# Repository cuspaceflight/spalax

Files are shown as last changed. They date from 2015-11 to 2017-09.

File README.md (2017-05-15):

# Spalax



This repository contains the schematics, PCB designs and firmware for a 10DOF IMU system.

## Components

- [Firmware](firmware) - Firmware for the various IMU boards
- [GUI](gui) - A 3D visualisation GUI which renders in realtime data sent from an attached IMU board
- [Shared](shared) - A static library providing common functionality between the various software components
- [Util](util) - A collection of useful C++, python and bash utilities
- [PCB](pcb) - The KiCad PCB files for the Spalax IMU boards

## Build Requirements

- GCC v4.8+
- CMake v3.2+
- arm-none-eabi-gcc (firmware build)
- xorg-dev libgl1-mesa-dev libfreetype6-dev libglew-dev libglm-dev (GUI build)
- GLFW v3+ (GUI build) - see [glfw-install.sh](util/bash/glfw-install.sh)

## Compilation

Having installed all the dependencies simply run from the root directory of the repo

```bash
git submodule update --init --recursive
./util/bash/travis-build.sh
```

This will configure and compile all the different components. If you only wish to configure a subset, just run the relevant section of [travis-build.sh](util/bash/travis-build.sh).

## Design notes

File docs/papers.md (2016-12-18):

[quadruped kalman filter design](http://biorob.epfl.ch/files/content/sites/biorob/files/users/195094/imports/report.pdf) 

[automatic and adaptive sensor calibration](http://ac.els-cdn.com/S0307904X07000297/1-s2.0-S0307904X07000297-main.pdf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)

[GPS/IMU Data Fusion](http://www.stats.ox.ac.uk/~caron/Publications/J_Information_Fusion_2004.pdf)

[Iterative calibration for triaxial accelerometers](http://www.ncbi.nlm.nih.gov/pmc/articles/PMC3436022/)

[Quaternion based kalman filter](http://ieeexplore.ieee.org/stamp/stamp.jsp?tp=&arnumber=4020379)

[High-Efficiency Low-Cost Accelerometer-Aided Gyroscope Calibration](http://ieeexplore.ieee.org/stamp/stamp.jsp?tp=&arnumber=5412920)

[Kalman filter introduction videos](http://studentdavestutorials.weebly.com/kalman-filter-with-matlab-code.html)

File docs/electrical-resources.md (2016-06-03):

# Resources for Electronics Design

## CPU

We plan to use the
[STM32F405VG](http://www.st.com/web/en/catalog/mmc/FM141/SC1169/SS1577/LN1035/PF252142?s_searchtype=keyword)
ARM Cortex-M4 based micro controller as the CPU for the board. Some useful
resources:

* [Datasheet](http://www.st.com/st-web-ui/static/active/en/resource/technical/document/datasheet/DM00037051.pdf)
* [Reference manual](http://www.st.com/web/en/resource/technical/document/reference_manual/DM00031020.pdf)
* [Programming manual](http://www.st.com/web/en/resource/technical/document/programming_manual/DM00046982.pdf)

For reference, STMicroelectronics make available the schematics for their "STM32F4Discovery" board from the 
[corresponding page](http://www.st.com/web/catalog/tools/FM116/SC959/SS1532/PF252419) on their website.

## Sensor modules

The main sensor module is a [ADIS16405BMLZ MEMS
Module](http://onecall.farnell.com/analog-devices/adis16405bmlz/ic-module-gyro-accel-mag-24pin/dp/1849515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).

* [Datasheet](http://www.farnell.com/datasheets/1914493.pdf)

The secondary sensor module is an MPU9250

* [Datasheet](<https://www.invensense.com/wp-content/uploads/2015/02/MPU-9250-Datasheet.pdf>)
* [Register Map](<https://www.invensense.com/wp-content/uploads/2015/02/MPU-9250-Register-Map.pdf>)
* [Internal Magnetomer Datasheet](<https://www.akm.com/akm/en/file/datasheet/AK8963C.pdf>)

## Other components

* [ADP3335 voltage regulator](http://www.analog.com/media/en/technical-documentation/data-sheets/ADP3335.pdf)
* [USBLC6-2 ESD protection](http://www.st.com/web/en/resource/technical/document/datasheet/CD00050750.pdf)

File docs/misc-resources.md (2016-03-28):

### Papers:

* [Stochastic modeling of MEMS sensors](http://www.cit.iit.bas.bg/cit_2010/v10-2/31-40.pdf)
* [Attitude Estimation Using Modified Rodrigues Parameters](http://ntrs.nasa.gov/archive/nasa/casi.ntrs.nasa.gov/19960035754.pdf)
* [Analog Device's Application Note on the EKF implementation in another of their sensors](http://www.analog.com/media/en/technical-documentation/application-notes/AN-1157.pdf)
* [A Survey of Nonlinear Attitude Estimation Methods](http://ancs.eng.buffalo.edu/pdf/ancs_papers/2007/att_survey07.pdf)

### Existing projects:

* https://github.com/sfwa/ukf
* [An existing sensor](https://www.bosch-sensortec.com/en/homepage/products_3/sensor_hubs/iot_solutions/bno055_1/bno055_4) which does sensor fusion whose SPI interface we may take inspiration from.
* https://github.com/kriswiner/BNO-055 - A driver for the above which does
    attitude estimation on an Arduino via a quaternion filter
* http://www.x-io.co.uk/res/doc/madgwick_internal_report.pdf - An efficient
    orientation filter for inertial and inertial/magnetic sensor arrays (Some
    existing work on putting this into some efficient embedded C)
    
### Other resources:

* [IMU quadrotor dataset](http://www.sfly.org/mav-datasets)
* [A Collection of Outdoor Robotic Datasets with centimeter-accuracy Ground Truth](http://www.mrpt.org/malaga_dataset_2009)
* [Handheld camera 6dof trajectories](http://webdav.is.mpg.de/pixel/benchmark4camerashake/)

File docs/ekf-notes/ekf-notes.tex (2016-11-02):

\documentclass[a4paperz]{paper}

\usepackage{amsmath}
\usepackage{amssymb}
\usepackage{microtype}
\usepackage{times}

\title{Some notes on Extended Kalman Filters for Spacecraft Attitude Estimation}
\author{Rich Wareham}

\begin{document}
\maketitle

\section{Introduction}

These notes provide a heavily abbreviated summary of the use of the extended
Kalman filter and modified Rodrigues rotation parametrisation in spacecraft
attitude estimation. More detailed information can be found in
\cite{crassidis1996attitude, karlgaard2009nonsingular} but it is hoped that this
note provides a concise reference for the concepts contained within those
papers.

We begin with a review of two common parametrisations for rotations in
$\mathbb{R}^3$, quaternions and the modified Rodrigues vector. We then define
the state vector used to represent the current state of the spacecraft and which
is updated by the Kalman filter. The various sensor measurement functions are
then defined and finally we outline the complete Kalman filter algorithm.

\section{Review of quaternions}

The set of quaternions is conventionally denoted as $\mathbb{Q}$. This set can
be associated with analogues of multiplication and addition to form a ring.  A
convenient parametrisation of a given quaternion is in terms of a
\emph{scalar} or ``real'' part and three independent \emph{vector} or
``imaginary'' parts:
$$
q \equiv q_1 + q_i \mathbf{i} + q_j \mathbf{j} + q_k \mathbf{k}
$$
where $q_{\{1,i,j,k\}} \in \mathbb{R}$ and
$$
\mathbf{i}^2 = \mathbf{j}^2 = \mathbf{k}^2 = \mathbf{ijk} = -1.
$$

A unit quaternion, $q$, is one where $q^2 = 1$. Quaternion conjugation is
defined analogously to complex numbers:
$$
\left(
	q_1 + q_i \mathbf{i} + q_j \mathbf{j} + q_k \mathbf{k}
\right)^* \triangleq
	q_1 - q_i \mathbf{i} - q_j \mathbf{j} - q_k \mathbf{k}
$$
It should be clear from the above that both $\mathbb{R}$ and $\mathbb{C}$ are
sub-groups of $\mathbb{Q}$.

We state without proof that the unit quaternion may be interpreted as
representing a rotation in $\mathbb{R}^3$. Identifying $\mathbf{i}$,
$\mathbf{j}$ and $\mathbf{k}$ with some Cartesian basis of $\mathbb{R}^3$ we may
bijectively map any vector $v \in \mathbb{R}^3$ to $\mathbb{Q}$. In so doing,
the transformation
$$
v' \leftarrow q \, v \, q^*
$$
with $q^2 = -1$ represents some rotation of $v$. Letting $\bar{n} = n_i
\mathbf{i} + n_j \mathbf{jk} + n_k \mathbf{k}$ be the unit vector pointing along
the axis of rotation and $\theta$ be the rotation angle, we find that the
quaternion representing the equivalent rotation is given by
$$
q = \cos\left(\theta / 2\right) + \sin\left(\theta / 2\right) \bar{n}.
$$

\section{Review of the modified Rodrigues parameterisation}

Below, we will be using the \emph{Modified Rodrigues Parameters} representation.
Letting $\left< q\right>_s$ and $\left< q\right>_v \equiv \left< q \right>_i
\mathbf{i} + \left< q\right>_j \mathbf{j} + \left< q\right>_k \mathbf{k}$ be the
scalar (real) and vector (imaginary) components of the quaternion $q$, we have
the MRP representation of $q$ defined to be
$$
\mbox{mrp}(q) \triangleq \frac{1}{1 + \left< q\right>_s} \left< q
\right>_v \equiv \bar{n} \tan \left( \frac{\theta}{4} \right)
$$
where $\bar{n}$ is the unit vector pointing along the axis of rotation and
$\theta$ is the angle of rotation. In particular, note that $\mbox{mrp}(1) =
\vec{0}$.

\section{Representation of spacecraft state}

In this section we outline the formation of the \emph{state vector}, $x_k$,
which we use to represent the state of the spacecraft at time instant $k$.

We firstly define two frames of reference. The \emph{reference frame} is the
absolute frame. Conventionally we may choose the $z$ direction to be ``up'' and
define $x$ and $y$ with respect to some horizontal reference. (We may choose $x$
to be East and $y$ to be North, for example.) The \emph{body frame} is defined
relative to the spacecraft. In this case $z$ may be along the principal thrust
axis and $x$ and $y$ may be defined with reference to some known point of
reference on the spacecraft body.

Attitudes of spacecraft are usually represented as rotations mapping the
reference frame to the spacecraft body frame. Define $q_k \in \mathbb{Q}$ to be
the unit quaternion representing the rotation from the reference frame to the
body frame at timestep $k$. Further let $\omega_k \in \mathbb{R}^3$ be the
reference frame angular velocity vector of the spacecraft at timestep $k$.

We use the notation $\dot{x}$ to denote the differential of $x$ with respect to
time. Hence we will use $\ddot{p}_k$ to represent the linear acceleration of the
spacecraft. For attitude estimation, it is assumed that this is simply the
acceleration due to gravity.

There is an issue with using the attitude as represented by a quaternion
directly in a Kalman filter. The interdependence of the four components of $q_k$
is highly non-linear and, relatedly, the four components are a redundant
parameterisation. We wish to use a quaternion representation, however, because
it does not suffer from singularities of representation.

To work around this problem we shall instead keep track of the
timestep-to-timestep \emph{error} in attitude, $\Delta q_k \in \mathbb{Q}$.
I.e., $q_k = \Delta q_k \, q_{k-1}$. Further we will represent $\Delta
q_k$ with the three-parameter MRP representation. As long as the error
remains far from the representation's singular points there shouldn't be a
problem. In the case of the MRP, this means that the spacecraft should not
rotate more than $180^\circ$ in one timestep.

We will be sensing orientation by integrating measurements from gyroscopes
assumed to have some bias. Let $b_k$
represent the gyro bias at timestep $k$ such that the gyro measurement
$\omega^{(g)}_k$ is related to the true body-frame angular velocity,
$\omega^{(b)}_k$ by
$$
\omega^{(g)}_k = \omega^{(b)}_k + b_k + \nu^{(g)}_k
$$
where $\nu^{(g)}_k$ is the gyro noise at time $k$ whose components are assumed
to be i.i.d. samples from some zero-mean Gaussian process. The gyro bias, $b_k$,
is assumed to be a Gaussian random walk. (I.e., $\dot{b}_k$ are drawn from some
stationary zero-mean Gaussian process.)

In order to allow for gyro bias in our model, we shall estimate the
instantaneous gyro bias $b_k$ as part of the state vector. Our complete state
vector is therefore
$$
x_k \triangleq \left[
	\mbox{mrp}(\Delta q_k), \omega_k, \dot{\omega}_k, b_k
\right]
$$
and has 12 components. The zero-noise kinematics of the state components may now
be written directly:
$$
\frac{\partial}{\partial t} \mbox{mrp}(\Delta q_k) = 0, \quad
\frac{\partial}{\partial t} \omega_k = \dot{\omega}_k, \quad
\frac{\partial}{\partial t} \dot{\omega}_k = 0, \quad
\frac{\partial}{\partial t} b_k = 0.
$$

We shall split estimates relating to timestep $k$ into \emph{a priori} and
\emph{a posteriori} classes. Estimates which are $\emph{a priori}$ are formed
from all measurements \emph{prior} to timestep $k$ whereas $\emph{a
posteriori}$ estimates additionally take into account measurements from timestep
$k$.

Our \emph{a priori} state prediction step is therefore a simple Euler integration:
$$
\hat{x}_{k|k-1} = f\left(\hat{x}_{k-1|k-1}; \Delta t\right)
\triangleq \hat{x}_{k-1|k-1} + \Delta t \frac{\partial}{\partial t}
\hat{x}_{k-1|k-1}.
$$

In addition we set $\mbox{mrp}(\hat{\Delta q}_{k|k-1}) = \vec{0}$ to reflect our
belief that the prediction error is zero and we also set
$\hat{\dot{\omega}}_{k|k-1} = \vec{0}$ to reflect our belief that there is no
imposed angular acceleration. In the case of active control, this last
assumption should be replaced with the angular acceleration vector due to
applied thrust.

The Jacobian of $f(\cdot)$ at $\hat{x}_{k-1|k-1}$ with respect to the state
vector components, $F_k$, may be written down directly from the definition of
the differential above.

For each time step, $k$, we wish to obtain the \emph{a posteriori} attitude
estimate $\hat{q}_{k|k}$. We can calculate it from the \emph{a priori} and
\emph{a posteriori} state estimates $\hat{x}_{k|k-1}$ and $\hat{x}_{k|k}$.
(Notice that in general we use $\hat{\cdot}$ to indicate the estimates of states
and their components as opposed to their ``true'' values.) Define the \emph{a
priori} estimate of attitude to be
$$
\hat{q}_{k|k-1} \triangleq q^{\Delta t}_{\hat{\omega}_{k-1|k-1}}
\hat{q}_{k-1|k-1}
$$
where $q_{\hat{\omega}_{k-1|k-1}}$ is a rotation around the axis aligned with
$\hat{\omega}_{k-1|k-1}$. The angle of the rotation is the magnitude of
$\hat{\omega}_{k-1|k-1}$.

The \emph{a posteriori} estimate of attitude is obtained by applying the
estimated error quaternion:
$$
\hat{q}_{k|k} \triangleq \hat{\Delta q}_{k|k} \hat{q}_{k|k-1}.
$$

\section{Measurement functions}

The accelerometer measurement function is
$$
h_a(x_k; \hat{q}_{k|k-1}) = q'_k \, g \, {q'_k}^*
$$
where $g$ is the vector acceleration due to gravity in the reference frame and
$q'_k \triangleq \hat{\Delta q}_{k|k-1} \, \hat{q}_{k|k-1}$. 

The gyroscope measurement function is
$$
h_g(x_k; \hat{q}_{k|k-1}) = q'_k \, \omega_k \, {q'_k}^* + b_k.
$$

The magnetometer measurement function is
$$
h_B(x_k;\hat{q}_{k|k-1}) = q'_k \, \frac{B}{|B|} \, {q'_k}^*
$$
where $B$ is the local reference-frame magnetic field vector.

Note that, in general, $g$ and $B$ are a function of $p_k$. For the sake of
considering attitude-only motion, we assume that they are fixed and known.

For each measurement function we may also write down the Jacobian, $H_k$,
centred on $\hat{x}_{k|k-1}$ with respect to the state vector components.

\section{The extended Kalman filter}

The extended Kalman filter (EKF) is a two stage estimation procedure. The
\emph{a priori} state estimate is formed from the \emph{a posteriori} estimate
from the previous time step. The \emph{a posteriori} estimate for the current
timestep is then computed by updating the \emph{a priori} estimate.

In addition to the estimate of state, an estimate of the covariance of the state
estimation error, $P_k$, is also maintained.

The Kalman filter assumes that the ``true'' state, $x_k$ evolves according to:
$$
x_k = f(x_{k-1}; q_{k-1}) + \nu^{(x)}_k
$$
where $\nu^{(x)}_k$ are samples from some zero-mean Gaussian process with
covariance $Q_k$. Similarly a measurement at timestep $k$, $z_k$ is assumed to
be given by
$$
z_k = h(x_k) + \nu^{(z)}_k
$$
where $h(\cdot)$ is the appropriate measurement function and $\nu^{(z)}_k$ are
samples from a zero mean Gaussian process with covariance $R_k$. Each different
sensor will have its own way of specifying $R_k$.

Letting $F_k$ and $H_k$ represent the Jacobians of $f(\cdot)$ and $h(\cdot)$
defined above, the EKF predict step is
\begin{align*}
	\hat{x}_{k|k-1} &= f(\hat{x}_{k-1|k-1}; \hat{q}_{k-1|k-1}) \\
	P_{k|k-1} &= F_{k-1} P_{k-1|k-1} F^T_{k-1} + Q_k
\end{align*}
where $P_{k|k-1}$ is the \emph{a priori} prediction error covariance at timestep
$k$, $P_{k-1|k-1}$ is the \emph{a posteriori} estimation error covariance at
timestep $k-1$ and $Q_k$ is the process noise covariance for timestep $k-1$.

A sensor measurement, $z_k$, with associated measurement function, $h(\cdot)$,
and sensor noise covariance $R_k$, is incorporated into the filter by way of the
update step. First compute the innovation and innnovation covariance:
\begin{align*}
	y_k &= z_k - h(\hat{x}_{k|k-1}; \hat{q}_{k|k-1})\\
	S_k &= H_k P_{k|k-1} H^T_k + R_k.
\end{align*}
Next we compute the Kalman gain:
$$ K_k = P_{k|k-1} H^T_k S^{-1}_k. $$
This gain is used to compute the \emph{a posteriori} state estimate mean and covariance:
\begin{align*}
	P_{k|k} &= P_{k|k-1} - K_k H_kP_{k|k-1}\\
	\hat{x}_{k|k} &= \hat{x}_{k|k-1} + K_k y_k.
\end{align*}

Multiple measurements at the same timestep may be handled by repeated updates
after the prediction step. The relations for $\hat{q}_{k|k-1}$ and
$\hat{q}_{k|k}$ were given above.

It is worth noting a curious property of $P_{k|k}$ in that it does not depend
on the data. (Assuming that each sensor's measurement covariance is
data-independent.) It follows that the state estimate covariance is entirely
pre-determined.

\section{Extensions}

These notes cover attitude-only motion. Extending the algorithm to include
linear motion is relatively straightforward. Firstly, we should add the
reference-frame linear position, $p_k$, velocity $\dot{p}_k$ and acceleration,
$\ddot{p}_k$ to the state vector. The prediction function $f(\cdot)$ and
associated Jacobian $F_k$ should be updated with the observation
$$
\frac{\partial}{\partial t} p_k = \dot{p}_k, \quad
\frac{\partial}{\partial t} \dot{p}_k = \ddot{p}_k, \quad
\frac{\partial}{\partial t} \ddot{p}_k = 0
$$
and the prior belief that $\hat{\ddot{p}}_k = \vec{0}$.

We shall assume that the reference frame is one which is stationary with respect
to the gravitational field so that our accelerometer measurement function now
becomes
$$
h_a(x_k; \hat{q}_{k|k-1}) = q'_k \, (\ddot{p}_k + g) \, {q'_k}^*
$$

In order for the state estimate covariance of linear position and velocity to
come down to some sensible value we also need some sensor measuring $p_k$ and
$\dot{p}_k$. This need not be massively accurate and could come from, e.g.,
GPS or be supplied externally.

\bibliographystyle{plain}
\bibliography{references}

\end{document}

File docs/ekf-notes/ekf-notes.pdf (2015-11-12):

# Some notes on Extended Kalman Filters for Spacecraft Attitude Estimation

## Rich Wareham

### 1 Introduction

These notes provide a heavily abbreviated summary of the use of the extended Kalman filter and modified Rodrigues rotation parametrisation in spacecraft attitude estimation. More detailed information can be found in [1, 2] but it is hoped that this note provides a concise reference for the concepts contained within those papers.
We begin with a review of two common parametrisations for rotations in R
3
, quaternions and the modified Rodrigues vector. We then define the state vector used to represent the current state of the spacecraft and which is updated by the Kalman filter. The various sensor measurement functions are then defined and finally we outline the complete Kalman filter algorithm.

### 2 Review of quaternions

The set of quaternions is conventionally denoted as Q. This set can be associated with analogues of multiplication and addition to form a ring. A convenient parametrisation of a given quaternion is in terms of a scalar or “real” part and three independent vector or “imaginary” parts:
q ≡ q1 + qii + qj j + qkk

where q{1,i,j,k} ∈ R and
i

2 = j

2 = k

2 = ijk = −1.

A unit quaternion, q, is one where q

2 = 1. Quaternion conjugation is defined analogously to complex numbers:

(q1 + qii + qj j + qkk)

∗ ≜ q1 − qii − qj j − qkk

It should be clear from the above that both R and C are sub-groups of Q.
We state without proof that the unit quaternion may be interpreted as representing a rotation in R
3

. Identifying i, j and k with some Cartesian basis of R 3 we may
bijectively map any vector v ∈ R
3

to Q. In so doing, the transformation

v

′ ← q v q∗

with q

2 = −1 represents some rotation of v. Letting n¯ = nii + nj jk + nkk be the unit vector pointing along the axis of rotation and θ be the rotation angle, we find that the quaternion representing the equivalent rotation is given by

q = cos (θ/2) + sin (θ/2) ¯n.

1

3 Review of the modified Rodrigues parameterisation | 2

### 3 Review of the modified Rodrigues parameterisation

Below, we will be using the Modified Rodrigues Parameters representation. Letting
⟨q⟩
s

and ⟨q⟩

v ≡ ⟨q⟩
i

i + ⟨q⟩
j

j + ⟨q⟩k k be the scalar (real) and vector (imaginary) components of the quaternion q, we have the MRP representation of q defined to be

mrp(q) ≜

1
1 + ⟨q⟩
s

⟨q⟩

v ≡ n¯ tan (
θ
4

)

where n¯ is the unit vector pointing along the axis of rotation and θ is the angle of rotation. In particular, note that mrp(1) = ⃗0.

### 4 Representation of spacecraft state

In this section we outline the formation of the state vector, xk, which we use to represent the state of the spacecraft at time instant k.
We firstly define two frames of reference. The reference frame is the absolute frame. Conventionally we may choose the z direction to be “up” and define x and y with respect to some horizontal reference. (We may choose x to be East and y to be North, for example.) The body frame is defined relative to the spacecraft. In this case z may be along the principal thrust axis and x and y may be defined with reference to some known point of reference on the spacecraft body.
Attitudes of spacecraft are usually represented as rotations mapping the reference frame to the spacecraft body frame. Define qk ∈ Q to be the unit quaternion representing the rotation from the reference frame to the body frame at timestep k. Further let ωk ∈ R
3 be the reference frame angular velocity vector of the spacecraft at timestep k. We use the notation x˙ to denote the differential of x with respect to time. Hence we will use p¨k to represent the linear acceleration of the spacecraft. For attitude estimation, it is assumed that this is simply the acceleration due to gravity.
There is an issue with using the attitude as represented by a quaternion directly in a Kalman filter. The interdependence of the four components of qk is highly non-linear and, relatedly, the four components are a redundant parameterisation. We wish to use a quaternion representation, however, because it does not suffer from singularities of representation.
To work around this problem we shall instead keep track of the timestep-to-timestep error in attitude, ∆qk ∈ Q. I.e., qk = ∆qk qk−1. Further we will represent ∆qk with the three-parameter MRP representation. As long as the error remains far from the representation’s singular points there shouldn’t be a problem. In the case of the MRP, this means that the spacecraft should not rotate more than 180◦
in one timestep.
We will be sensing orientation by integrating measurements from gyroscopes assumed to have some bias. Let bk represent the gyro bias at timestep k such that the gyro measurement ω

(g)
k

is related to the true body-frame angular velocity, ω

(b)
k

by

ω

(g)
k = ω

(b)
k + bk + ν

(g)
k

where ν

(g)
k

is the gyro noise at time k whose components are assumed to be i.i.d. samples from some zero-mean Gaussian process. The gyro bias, bk, is assumed to be a Gaussian random walk. (I.e., ḃk are drawn from some stationary zero-mean Gaussian process.)

5 Measurement functions | 3

In order to allow for gyro bias in our model, we shall estimate the instantaneous gyro bias bk as part of the state vector. Our complete state vector is therefore

xk ≜ [mrp(∆qk), ωk, ω˙ k, bk]

and has 12 components. The zero-noise kinematics of the state components may now be written directly:

∂
∂tmrp(∆qk) = 0,

∂
∂tωk = ˙ωk,

∂
∂tω˙ k = 0,

∂
∂t bk = 0.

We shall split estimates relating to timestep k into a priori and a posteriori classes. Estimates which are a priori are formed from all measurements prior to timestep k whereas a posteriori estimates additionally take into account measurements from timestep k.
Our a priori state prediction step is therefore a simple Euler integration:

xˆk|k−1 = f

(
xˆk−1|k−1; ∆t

)
≜ xˆk−1|k−1 + ∆t

∂
∂txˆk−1|k−1.

In addition we set mrp(∆ˆqk|k−1
) = ⃗0 to reflect our belief that the prediction error is zero and we also set ωˆ˙ k|k−1 = ⃗0 to reflect our belief that there is no imposed angular acceleration. In the case of active control, this last assumption should be replaced with the angular acceleration vector due to applied thrust.
The Jacobian of f(·) at xˆk−1|k−1 with respect to the state vector components, Fk, may be written down directly from the definition of the differential above.
For each time step, k, we wish to obtain the a posteriori attitude estimate qˆk|k. We can calculate it from the a priori and a posteriori state estimates xˆk|k−1 and xˆk|k. (Notice that in general we usê· to indicate the estimates of states and their components as opposed to their “true” values.) Define the a priori estimate of attitude to be

qˆk|k−1 ≜ q
∆t
ωˆk−1|k−1

qˆk−1|k−1

where qωˆk−1|k−1

is a rotation around the axis aligned with ωˆk−1|k−1. The angle of the rotation is the magnitude of ωˆk−1|k−1.
The a posteriori estimate of attitude is obtained by applying the estimated error quaternion:
qˆk|k ≜ ∆ˆqk|k
qˆk|k−1.

### 5 Measurement functions

The accelerometer measurement function is

ha(xk; ˆqk|k−1) = q

′
k

g q′
k

∗

where g is the vector acceleration due to gravity in the reference frame and q

′

k ≜
∆ˆqk|k−1
qˆk|k−1.
The gyroscope measurement function is

hg(xk; ˆqk|k−1) = q

′
k ωk q

′
k

∗ + bk.

6 The extended Kalman filter | 4

The magnetometer measurement function is

hB(xk; ˆqk|k−1) = q

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
where B is the local reference-frame magnetic field vector.
Note that, in general, g and B are a function of pk. For the sake of considering attitude-only motion, we assume that they are fixed and known.
For each measurement function we may also write down the Jacobian, Hk, centred on xˆk|k−1 with respect to the state vector components.

### 6 The extended Kalman filter

The extended Kalman filter (EKF) is a two stage estimation procedure. The a priori state estimate is formed from the a posteriori estimate from the previous time step. The a posteriori estimate for the current timestep is then computed by updating the a priori estimate.
In addition to the estimate of state, an estimate of the covariance of the state estimation error, Pk, is also maintained.
The Kalman filter assumes that the “true” state, xk evolves according to:

xk = f(xk−1; qk−1) + ν

(x)
k

where ν

(x)
k

are samples from some zero-mean Gaussian process with covariance Qk. Similarly a measurement at timestep k, zk is assumed to be given by

zk = h(xk) + ν

(z)
k

where h(·) is the appropriate measurement function and ν

(z)
k

are samples from a zero
mean Gaussian process with covariance Rk. Each different sensor will have its own way of specifying Rk.
Letting Fk and Hk represent the Jacobians of f(·) and h(·) defined above, the EKF predict step is

xˆk|k−1 = f(ˆxk−1|k−1; ˆqk−1|k−1)

Pk|k−1 = Fk−1Pk−1|k−1F

T
k−1 + Qk

where Pk|k−1 is the a priori prediction error covariance at timestep k, Pk−1|k−1 is the a posteriori estimation error covariance at timestep k − 1 and Qk is the process noise covariance for timestep k − 1.
A sensor measurement, zk, with associated measurement function, h(·), and sensor noise covariance Rk, is incorporated into the filter by way of the update step. First compute the innovation and innnovation covariance:

yk = zk − h(ˆxk|k−1; ˆqk|k−1)

Sk = HkPk|k−1HT
k + Rk.

Next we compute the Kalman gain:

Kk = Pk|k−1HT
k S

−1
k

7 Extensions | 5

This gain is used to compute the a posteriori state estimate mean and covariance:

Pk|k = Pk|k−1 − KkHkPk|k−1
xˆk|k = ˆxk|k−1 + Kkyk.

Multiple measurements at the same timestep may be handled by repeated updates after the prediction step. The relations for qˆk|k−1 and qˆk|k were given above.
It is worth noting a curious property of Pk|k in that it does not depend on the data. (Assuming that each sensor’s measurement covariance is data-independent.) It follows that the state estimate covariance is entirely pre-determined.

### 7 Extensions

These notes cover attitude-only motion. Extending the algorithm to include linear motion is relatively straightforward. Firstly, we should add the reference-frame linear position, pk, velocity p˙k and acceleration, p¨k to the state vector. The prediction function f(·) and associated Jacobian Fk should be updated with the observation

∂
∂tpk = ṗk,

∂
∂tp˙k = ¨pk,

∂
∂tp¨k = 0

and the prior belief that pˆ¨k = ⃗0.
We shall assume that the reference frame is one which is stationary with respect to the gravitational field so that our accelerometer measurement function now becomes

ha(xk; ˆqk|k−1) = q

′
k

(¨pk + g) q

′
k

∗

In order for the state estimate covariance of linear position and velocity to come down to some sensible value we also need some sensor measuring pk and p˙k. This need not be massively accurate and could come from, e.g., GPS or be supplied externally.

### References

[1] John L Crassidis and FL Markiey. Attitude estimation using modified rodrigues parameters, 1996.
[2] Christopher D Karlgaard and Hanspeter Schaub. Nonsingular attitude filtering using modified rodrigues parameters. The Journal of the Astronautical Sciences, 57(4):777–791, 2009.

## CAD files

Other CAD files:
pcb/Gerbers/IMU-F.Paste.dxf

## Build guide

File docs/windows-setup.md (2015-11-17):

# Windows specific setup instructions

## Environment Setup

Follow the instructions [here](http://www.jann.cc/2013/10/10/embedded_development_with_open_source_tools_on_windows.html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) to install the GCC ARM toolchain, MinGW and MSYS

## GUI Build Configuration

Follow the instructions in [README.md](../README.md)

## Firmware Build Configuration

* Make sure you have the [ARM GCC toolchain](https://launchpad.net/gcc-arm-embedded) installed and added to your PATH
* Open the CMake GUI
* Set the source code the root directory of this repo
* Set the build directory to ${ROOT_DIR}/Avionics.Firmware.Build
* Click Configure - if it asks to create the directory select yes
* For the generator select 'MinGW Makefiles'
* Select 'Specify toolchain file for cross-compiling'
* Click Next
* Specify $[ROOT_DIR}/Toolchain-arm-none-eabi.cmake
* Click Finish
* Configuration will fail as you haven't selected the configuration to build
* Select the BUILD_FIRMWARE checkbox and click configure again
* Change the MAKE_COMMAND settings to 'mingw32-make'
* Click Configure again
* Finally click Generate
* Avionics.Firmware.Build should now contain the files to build the Firmware

## Firmware Build

* Open mintty and navigate to ${ROOT_DIR}/Avionics.Firmware.Build you just created
* Type 'mingw32-make' to build everything
* CMake suppresses Make standard output and so I recommend adding 'VERBOSE=1'

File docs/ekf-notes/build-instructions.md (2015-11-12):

# Building LaTeX documents

Although the PDF for the LaTeX documents in this directory are also included, it
is worth adding a note on how they're created. On my (@rjw57) machine, one can
build the PDFs via:
```console
$ xelatex ekf-notes && bibtex ekf-notes && xelatex ekf-notes && xelatex ekf-notes
```
The repeated calls to ``xelatex`` being necessary due to the interesting way TeX
attempts to require only one pass over the file when typesetting.

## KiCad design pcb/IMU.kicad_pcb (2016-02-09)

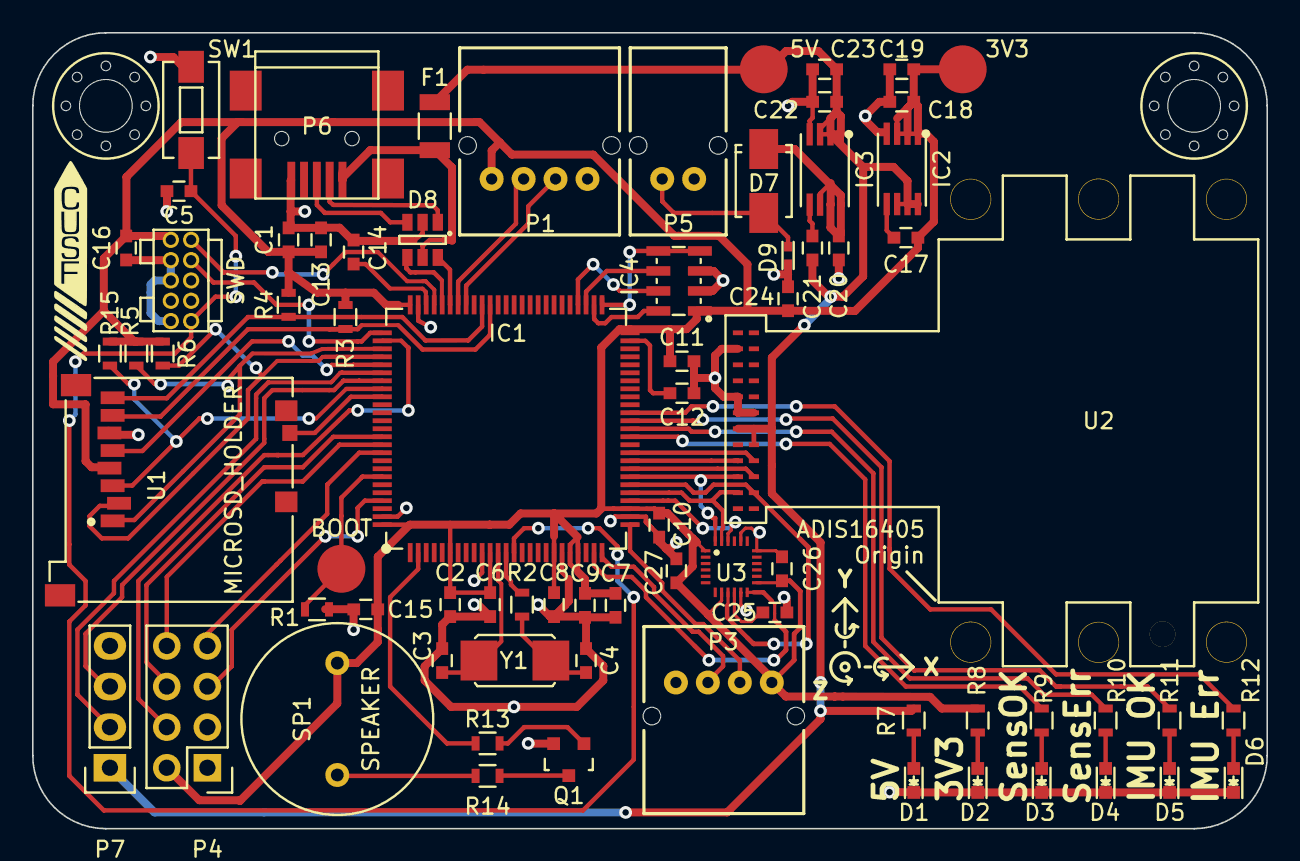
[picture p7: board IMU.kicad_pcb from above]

Board: 2 copper layers, 77.2 x 49.8 mm, 75 parts (0 on the bottom side), 66 nets.

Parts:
3V3: 3V3; Measurement_Point_Round-SMD-Pad_Big
5V: 5V; Measurement_Point_Round-SMD-Pad_Big
BOOT: BOOT0; Measurement_Point_Round-SMD-Pad_Big
C1, C19, C23: 10µ; C_0603
C2, C5, C6, C8, C10, C11, C13, C15, C16, C24, C25, C27: 100n; C_0603
C3, C4: 15p; C_0603
C7, C18, C20, C22: 1µ; C_0603
C9, C26: 10n; C_0603
C12, C14: 2µ2; C_0603
C17, C21: 1n; C_0603
D1, D2, D3, D5: LED_GREEN; LED-0603
D4, D6: LED_RED; LED-0603
D7: S1A; SMA_Standard
D8: USBLC6-2; SOT-23-6
D9: CGA0402MLC-12G; R0402
F1: 500mA; MC33191
IC1: STM32F405VGT; LQFP100
IC2: ADP3335ARMZ-3.3; MSOP8
IC3: ADP3335ARMZ-5; MSOP8
IC4: MS5611-01BA03; MS5611-01BA
M3_MOUNT, M3_MOUNT#2: VAL**; M3_MOUNT
P1: UART1; S04B-PASK-2
P2: SWD; FTSH-105-01-F-D-K
P3: UART2; S04B-PASK-2
P4: SPI; Pin_Header_Straight_2x04
P5: BATTERY; S02B-PASK-2
P6: USB_OTG; USB_Mini-B
P7: CAN BUS; Pin_Header_Straight_1x04
Q1: Q_NMOS_GSD_PSV; SOT-23
R1: 10K; R_0603
R2, R13: 100; R_0603
R3, R4, R5, R6, R15: 47k; R_0603
R7: 1k; R_0603
R8, R9, R10, R11, R12: 510; R_0603
R14: 10; R_0603
SP1: SPEAKER; ABI-042-RC
SW1: SW_PUSH; SW_SPST_EVQPE1
U1: MICROSD_HOLDER; MEM2051
U2: ADIS16405BMLZ
U3: MOTION/POSITION-MPU-9250(QFN24); QFN24G-0.4-3X3MM
Y1: 8M; XTAL50x32

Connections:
+3V3: 3V3.1, C1.1, C2.1, C6.1, C7.1, C8.1, C9.1, C10.1, C11.1, C13.1, C15.1, C16.1, C17.1, C18.1, C19.1, C24.1, C26.2, C27.1, IC1.6, IC1.11, IC1.19, IC1.21, IC1.22, IC1.28, IC1.50, IC1.75, IC1.100, IC2.1, IC2.2, IC2.3, IC4.1, P1.1, P2.1, P3.1, P4.2, R3.1, R4.1, R5.1, R6.1, R8.2, R15.1, SP1.1, U1.4, U3.1, U3.8, U3.13
+5V: 5V.1, C21.1, C22.1, C23.1, F1.2, IC2.6, IC2.7, IC2.8, IC3.1, IC3.2, IC3.3, P7.1, R7.2, U2.10, U2.11, U2.12
+BATT: C20.1, D7.1, IC3.6, IC3.7, IC3.8
/Altimeter/ALT_CSB: IC1.51, IC4.4, IC4.5
/Altimeter/ALT_SCLK: IC1.52, IC4.8
/Altimeter/ALT_SDI: IC1.54, IC4.7
/Altimeter/ALT_SDO: IC1.53, IC4.6
/BOOT0: BOOT.1, IC1.94, R1.2
/CAN1_RX: IC1.81, P7.2
/CAN1_TX: IC1.82, P7.3
/DATA_RDY: IC1.97, P4.5
/IntertialSensors/ADIS_IRQ: IC1.34, U2.7
/IntertialSensors/MISO: IC1.31, U2.4, U3.9
/IntertialSensors/MOSI: IC1.32, U2.5, U3.24
/IntertialSensors/MPU_IRQ: IC1.24, U3.12
/IntertialSensors/SCLK: IC1.30, U2.3, U3.23
/IntertialSensors/~ADIS_RESET: IC1.35, U2.8
/IntertialSensors/~ADIS_SS: IC1.33, U2.6
/IntertialSensors/~MPU_SS: IC1.29, U3.22
/Power/USB5V: D8.5, F1.1, P6.1
/SDCard/CARD_DETECT: IC1.84, U1.9
/SDCard/SDIO_CK: IC1.80, U1.5
/SDCard/SDIO_CMD: IC1.83, R15.2, U1.3
/SDCard/SDIO_D0: IC1.65, R3.2, U1.7
/SDCard/SDIO_D1: IC1.66, R4.2, U1.8
/SDCard/SDIO_D2: IC1.78, R5.2, U1.1
/SDCard/SDIO_D3: IC1.79, R6.2, U1.2
/SPI3_MISO: IC1.90, P4.8
/SPI3_MOSI: IC1.91, P4.7
/SPI3_NSS: IC1.77, P4.4
/SPI3_SCK: IC1.89, P4.6
/SWDCLK: IC1.76, P2.4
/SWDIO: IC1.72, P2.2
/StatusIndicators/Buzzer: IC1.2, R13.2
/StatusIndicators/IMU: IC1.39, R11.2
/StatusIndicators/Sensors: IC1.37, R9.2
/StatusIndicators/~IMU: IC1.40, R12.2
/StatusIndicators/~Sensors: IC1.38, R10.2
/USART1_RX: IC1.69, P1.2
/USART1_TX: IC1.68, P1.3
/USART2_RX: IC1.26, P3.2
/USART2_TX: IC1.25, P3.3
/USB/OTG_DS_DP: D8.4, IC1.71
/USB/OTG_FS_DM: D8.6, IC1.70
/~RST: C5.1, IC1.14, P2.10, SW1.2
GND: C1.2, C2.2, C3.2, C4.2, C5.2, C6.2, C7.2, C8.2, C9.2, C10.2, C11.2, C12.2, C13.2, C14.2, C15.2, C16.2, C18.2, C19.2, C20.2, C22.2, C23.2, C24.2, C25.1, C26.1, C27.2, D1.1, D2.1, D3.1, D4.1, D5.1, D6.1, D8.2, D9.1, IC1.10, IC1.20, IC1.27, IC1.74, IC1.99, IC2.4, IC3.4, IC4.2, IC4.3, P1.4, P2.3, P2.5, P2.9, P3.4, P4.1, P4.3, P5.2, P6.5, P7.4, Q1.2, R1.1, SW1.1, U1.6, U2.13, U2.14, U2.15, U2.21, U3.11, U3.18, U3.20
unnamed: C3.1, IC1.12, Y1.1
unnamed: C4.1, R2.2, Y1.2
unnamed: C12.1, IC1.49
unnamed: C14.1, IC1.73
unnamed: C17.2, IC2.5
unnamed: C21.2, IC3.5
unnamed: C25.2, U3.10
unnamed: D1.2, R7.1
unnamed: D2.2, R8.1
unnamed: D3.2, R9.1
unnamed: D4.2, R10.1
unnamed: D5.2, R11.1
unnamed: D6.2, R12.1
unnamed: D7.2, D9.2, P5.1
unnamed: D8.1, P6.2
unnamed: D8.3, P6.3
unnamed: IC1.13, R2.1
unnamed: Q1.1, R13.1
unnamed: Q1.3, R14.1
unnamed: R14.2, SP1.2

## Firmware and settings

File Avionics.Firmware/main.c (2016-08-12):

#include "ch.h"
#include "hal.h"
#include "state_estimate.h"
#include "mpu9250.h"
#include "ms5611.h"
#include "adis16405.h"
#include "badthinghandler.h"
#include "serialconsole.h"
#include "messaging.h"
#include "usb_telemetry.h"
#include "telemetry_allocator.h"
#include "checksum.h"
#include "avionics_config.h"
#include "state_estimate.h"
#include "calibration.h"

#define USE_USB_TELEMETRY

static WORKING_AREA(waMPU, 1024);
static WORKING_AREA(waBadThing, 1024);
static WORKING_AREA(waMS5611, 768);
static WORKING_AREA(waCalibration, 512);
//static WORKING_AREA(waADIS, 1024);
static WORKING_AREA(waStateEstimation, 2048);

#ifdef USE_USB_TELEMETRY
static WORKING_AREA(waUSBTransmit, 512);
static WORKING_AREA(waUSBReceive, 512);
#else
static WORKING_AREA(waUSB, 1024);
#endif


/*
 * Set up pin change interrupts for the various sensors that react to them.
 */
static const EXTConfig extcfg = { {
					  { EXT_CH_MODE_DISABLED, NULL }, /* Pin 0 */
					  { EXT_CH_MODE_AUTOSTART | EXT_CH_MODE_RISING_EDGE | EXT_MODE_GPIOA, mpu9250_wakeup }, /* Pin 1 */
					  { EXT_CH_MODE_DISABLED, NULL }, /* Pin 2 */
					  { EXT_CH_MODE_DISABLED, NULL }, /* Pin 3 */
					  { EXT_CH_MODE_DISABLED, NULL }, /* Pin 4 */
					  { EXT_CH_MODE_DISABLED, NULL }, /* Pin 5 */
					  { EXT_CH_MODE_DISABLED, NULL }, /* Pin 6 */
					  { EXT_CH_MODE_DISABLED, NULL }, /* Pin 7 */
					  { EXT_CH_MODE_DISABLED, NULL }, /* Pin 8 */
					  { EXT_CH_MODE_DISABLED, NULL }, /* Pin 9 */
					  { EXT_CH_MODE_DISABLED, NULL }, /* Pin 10*/
					  { EXT_CH_MODE_DISABLED, NULL }, /* Pin 11*/
					  { EXT_CH_MODE_DISABLED, NULL }, /* Pin 12*/
					  { EXT_CH_MODE_DISABLED, NULL }, /* Pin 13*/
					  { EXT_CH_MODE_DISABLED, NULL }, /* Pin 14*/
					  { EXT_CH_MODE_DISABLED, NULL }, /* Pin 15*/
					  { EXT_CH_MODE_DISABLED, NULL }, /* Pin 16*/
					  { EXT_CH_MODE_DISABLED, NULL }, /* Pin 17*/
					  { EXT_CH_MODE_DISABLED, NULL }, /* Pin 18*/
					  { EXT_CH_MODE_DISABLED, NULL }, /* Pin 19*/
					  { EXT_CH_MODE_DISABLED, NULL }, /* Pin 20*/
					  { EXT_CH_MODE_DISABLED, NULL }, /* Pin 21*/
					  { EXT_CH_MODE_DISABLED, NULL } /* Pin 22*/
				  } };

const avionics_config_t local_config = { telemetry_origin_imu, NULL };

int main(void) {
	halInit();
	chSysInit();
	chRegSetThreadName("Main");

	component_state_start();
	checksum_init();
	telemetry_allocator_start();
	messaging_start();



	//chThdCreateStatic(waMission, sizeof(waMission), NORMALPRIO, mission_thread, NULL);
	chThdCreateStatic(waBadThing, sizeof(waBadThing), NORMALPRIO, bthandler_thread, NULL);
	chThdCreateStatic(waMPU, sizeof(waMPU), NORMALPRIO, mpu9250_thread, NULL);
	chThdCreateStatic(waMS5611, sizeof(waMS5611), NORMALPRIO, ms5611_thread, NULL);
	chThdCreateStatic(waCalibration, sizeof(waCalibration), NORMALPRIO, calibration_thread, NULL);
	//chThdCreateStatic(waADIS, sizeof(waADIS), NORMALPRIO, adis16405_thread, NULL);
    chThdCreateStatic(waStateEstimation, sizeof(waStateEstimation), NORMALPRIO, state_estimate_thread, NULL);

    #ifdef USE_USB_TELEMETRY
        usb_telemetry_start();

    	chThdCreateStatic(waUSBReceive, sizeof(waUSBReceive), NORMALPRIO, usb_telemetry_receive_thread, NULL);
    	chThdCreateStatic(waUSBTransmit, sizeof(waUSBTransmit), NORMALPRIO, usb_telemetry_transmit_thread, NULL);
    #else
    	chThdCreateStatic(waUSB, sizeof(waUSB), NORMALPRIO, serial_console_thread, NULL);
    #endif

	extStart(&EXTD1, &extcfg);

	while (true) {
		chThdSleepMilliseconds(TIME_INFINITE);
	}
}

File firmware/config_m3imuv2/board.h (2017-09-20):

/*
    ChibiOS - Copyright (C) 2006..2016 Giovanni Di Sirio
    Licensed under the Apache License, Version 2.0 (the "License");
    you may not use this file except in compliance with the License.
    You may obtain a copy of the License at
    http://www.apache.org/licenses/LICENSE-2.0
    Unless required by applicable law or agreed to in writing, software
    distributed under the License is distributed on an "AS IS" BASIS,
    WITHOUT WARRANTIES OR CONDITIONS OF ANY KIND, either express or implied.
    See the License for the specific language governing permissions and
    limitations under the License.
*/

/*
    Generated by gen-board.h.py based on ../../firmware/config_m3imuv2/board.yaml
*/

#ifndef _BOARD_H_
#define _BOARD_H_


/*
    Setup for M3IMU
*/

/*
    Board identifier
*/
#define BOARD_M3IMU
#define BOARD_NAME                     "M3IMU"

/*
    Board oscillators-related settings.
*/
#if !defined(STM32_LSECLK)
#define STM32_LSECLK                   0U
#endif

#if !defined(STM32_HSECLK)
#define STM32_HSECLK                   26000000U
#endif

/*
    Board voltages
    Required for performance limits calculation.
*/
#define STM32_VDD                      330U

/*
    MCU type as defined in the ST header.
*/
#ifndef STM32F405xx
#define STM32F405xx
#endif
/*
    IO pins assignments.
*/

#define GPIOA_PIN0                     0U
#define GPIOA_LED_RED                  1U
#define GPIOA_LED_GREEN                2U
#define GPIOA_PIN3                     3U
#define GPIOA_PIN4                     4U
#define GPIOA_BARO_SCLK                5U
#define GPIOA_BARO_SDO                 6U
#define GPIOA_BARO_SDI                 7U
#define GPIOA_PIN8                     8U
#define GPIOA_USB_DETECT               9U
#define GPIOA_PIN10                    10U
#define GPIOA_OTG_FS_DM                11U
#define GPIOA_OTG_FS_DP                12U
#define GPIOA_JTMS                     13U
#define GPIOA_JTCK                     14U
#define GPIOA_JTDI                     15U

#define GPIOB_PIN0                     0U
#define GPIOB_PIN1                     1U
#define GPIOB_PIN2                     2U
#define GPIOB_JTDO                     3U
#define GPIOB_NJTRST                   4U
#define GPIOB_PIN5                     5U
#define GPIOB_PIN6                     6U
#define GPIOB_PIN7                     7U
#define GPIOB_CAN_RX                   8U
#define GPIOB_CAN_TX                   9U
#define GPIOB_PIN10                    10U
#define GPIOB_MPU_IRQ                  11U
#define GPIOB_MPU_CS                   12U
#define GPIOB_IMU_SCLK                 13U
#define GPIOB_IMU_MISO                 14U
#define GPIOB_IMU_MOSI                 15U

#define GPIOC_PIN0                     0U
#define GPIOC_PIN1                     1U
#define GPIOC_PIN2                     2U
#define GPIOC_PIN3                     3U
#define GPIOC_BARO_CS                  4U
#define GPIOC_PIN5                     5U
#define GPIOC_PIN6                     6U
#define GPIOC_PIN7                     7U
#define GPIOC_SD_DAT0                  8U
#define GPIOC_SD_DAT1                  9U
#define GPIOC_SD_DAT2                  10U
#define GPIOC_SD_DAT3                  11U
#define GPIOC_SD_CLK                   12U
#define GPIOC_PIN13                    13U
#define GPIOC_PIN14                    14U
#define GPIOC_PIN15                    15U

#define GPIOD_PIN0                     0U
#define GPIOD_PIN1                     1U
#define GPIOD_SD_CMD                   2U
#define GPIOD_PIN3                     3U
#define GPIOD_PIN4                     4U
#define GPIOD_PIN5                     5U
#define GPIOD_PIN6                     6U
#define GPIOD_PIN7                     7U
#define GPIOD_PIN8                     8U
#define GPIOD_PIN9                     9U
#define GPIOD_PIN10                    10U
#define GPIOD_PIN11                    11U
#define GPIOD_PIN12                    12U
#define GPIOD_PIN13                    13U
#define GPIOD_PIN14                    14U
#define GPIOD_PIN15                    15U

#define GPIOE_PIN0                     0U
#define GPIOE_PIN1                     1U
#define GPIOE_PIN2                     2U
#define GPIOE_PIN3                     3U
#define GPIOE_PIN4                     4U
#define GPIOE_PIN5                     5U
#define GPIOE_PIN6                     6U
#define GPIOE_PIN7                     7U
#define GPIOE_PIN8                     8U
#define GPIOE_PIN9                     9U
#define GPIOE_PIN10                    10U
#define GPIOE_PIN11                    11U
#define GPIOE_PIN12                    12U
#define GPIOE_PIN13                    13U
#define GPIOE_PIN14                    14U
#define GPIOE_PIN15                    15U
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

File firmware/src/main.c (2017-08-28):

#include <messaging_all.h>
#include <util/board_config.h>
#include <file_telemetry.h>
#include "mpu9250.h"
#include "ms5611.h"
#include "adis16405.h"
#include "ublox.h"
#include "badthinghandler.h"
#include "spalaxconf.h"
#include "util/board_config.h"

static THD_WORKING_AREA(waMPU, 256);
static THD_WORKING_AREA(waBadThing, 256);
static THD_WORKING_AREA(waMS5611, 256);
static THD_WORKING_AREA(waGPS, 1024);
#if BUILD_ADIS
static THD_WORKING_AREA(waADIS, 256);
#endif

#if BUILD_STATE_ESTIMATORS
#include <state/state_estimate.h>
// This is possibly more than it needs - but can be tweaked later
// It will need substantially more than other threads
static THD_WORKING_AREA(waStateEstimators, 4086 * 4);
#endif

int main(void) {
    halInit();
    chSysInit();
    chRegSetThreadName("Main");

    messaging_all_start();

    extStart(&EXTD1, &extcfg);

    board_config_t *config = getBoardConfig();

    chThdCreateStatic(waBadThing, sizeof(waBadThing), NORMALPRIO, bthandler_thread, NULL);

#if FILE_TELEMETRY_OUTPUT_ENABLED
    if (config->has_sdcard)
        file_telemetry_output_start("log.m3tel", false);
#endif

    if (config->has_ms5611)
        chThdCreateStatic(waMS5611, sizeof(waMS5611), NORMALPRIO, ms5611_thread, NULL);

    if (config->has_mpu9250)
        chThdCreateStatic(waMPU, sizeof(waMPU), NORMALPRIO, mpu9250_thread, NULL);

    if (config->has_gps)
        chThdCreateStatic(waGPS, sizeof(waGPS), NORMALPRIO, ublox_thread, NULL);
#if BUILD_ADIS
    if (config->has_adis)
        chThdCreateStatic(waADIS, sizeof(waADIS), NORMALPRIO, adis16405_thread, NULL);
#endif
#if BUILD_STATE_ESTIMATORS
    if (config->run_state_estimators)
        chThdCreateStatic(waStateEstimators, sizeof(waStateEstimators), NORMALPRIO, state_estimate_thread, NULL);
#endif
    while (true) {
        chThdSleepMilliseconds(TIME_INFINITE);
    }
}

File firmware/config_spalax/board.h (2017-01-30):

/*
 * M2FC ChibiOS Board definition file.
*/

#ifndef _BOARD_H_
#define _BOARD_H_

/*
 * Board identifier.
 */
#define BOARD_M2FC
#define BOARD_NAME                  "SPALAX"


/*
 * Board oscillators-related settings.
 */
#if !defined(STM32_LSECLK)
#define STM32_LSECLK                0
#endif

#if !defined(STM32_HSECLK)
#define STM32_HSECLK                8000000
#endif

/*
 * Board voltages.
 * Required for performance limits calculation.
 */
#define STM32_VDD                   330

/*
 * MCU type as defined in the ST header.
 */

#ifndef STM32F405xx
#define STM32F405xx
#endif

/*
 * Disable MCU's VBUS sensing. (Otherwise VBUS would have to be wired to PA9.)
 */
#define BOARD_OTG_NOVBUSSENS

/*
 * IO pins assignments.
 */
#define GPIOA_PIN0                  0
#define GPIOA_MPU_IRQ               1
#define GPIOA_USART2_TX             2
#define GPIOA_USART2_RX             3
#define GPIOA_MPU_NSS               4
#define GPIOA_IMU_SCK               5
#define GPIOA_IMU_MISO              6
#define GPIOA_IMU_MOSI              7
#define GPIOA_PIN8                  8
#define GPIOA_USART1_TX             9
#define GPIOA_USART1_RX             10
#define GPIOA_OTG_FS_DM             11
#define GPIOA_OTG_DS_DP             12
#define GPIOA_SWDIO                 13
#define GPIOA_SWCLK                 14
#define GPIOA_ESPI_NSS              15

#define GPIOB_ADIS_NRESET           0
#define GPIOB_PIN1                  1
#define GPIOB_STAT_SENSORS          2
#define GPIOB_ESPI_SCK              3
#define GPIOB_ESPI_MISO             4
#define GPIOB_ESPI_MOSI             5
#define GPIOB_PIN6                  6
#define GPIOB_PIN7                  7
#define GPIOB_PIN8                  8
#define GPIOB_PIN9                  9
#define GPIOB_PIN10                 10
#define GPIOB_PIN11                 11
#define GPIOB_ALT_NSS               12
#define GPIOB_ALT_SCK               13
#define GPIOB_ALT_MISO              14
#define GPIOB_ALT_MOSI              15

#define GPIOC_PIN0                  0
#define GPIOC_PIN1                  1
#define GPIOC_PIN2                  2
#define GPIOC_PIN3                  3
#define GPIOC_ADIS_NSS              4
#define GPIOC_ADIS_IRQ              5
#define GPIOC_PIN6                  6
#define GPIOC_PIN7                  7
#define GPIOC_SD_DAT0               8
#define GPIOC_SD_DAT1               9
#define GPIOC_SD_DAT2               10
#define GPIOC_SD_DAT3               11
#define GPIOC_SD_CLK                12
#define GPIOC_PIN13                 13
#define GPIOC_PIN14                 14
#define GPIOC_PIN15                 15

#define GPIOD_CAN1_RX               0
#define GPIOD_CAN1_TX               1
#define GPIOD_SD_CMD                2
#define GPIOD_SD_CD                 3
#define GPIOD_PIN4                  4
#define GPIOD_PIN5                  5
#define GPIOD_PIN6                  6
#define GPIOD_PIN7                  7
#define GPIOD_PIN8                  8
#define GPIOD_PIN9                  9
#define GPIOD_PIN10                 10
#define GPIOD_PIN11                 11
#define GPIOD_PIN12                 12
#define GPIOD_PIN13                 13
#define GPIOD_PIN14                 14
#define GPIOD_PIN15                 15

#define GPIOE_ESPI_DRDY             0
#define GPIOE_PIN1                  1
#define GPIOE_PIN2                  2
#define GPIOE_STAT_BUZZER           3
#define GPIOE_PIN4                  4
#define GPIOE_PIN5                  5
#define GPIOE_PIN6                  6
#define GPIOE_STAT_NSENSORS         7
#define GPIOE_STAT_IMU              8
#define GPIOE_STAT_NIMU             9
#define GPIOE_PIN10                 10
#define GPIOE_PIN11                 11
#define GPIOE_PIN12                 12
#define GPIOE_PIN13                 13
#define GPIOE_PIN14                 14
#define GPIOE_PIN15                 15

#define GPIOF_PIN0                  0
#define GPIOF_PIN1                  1
#define GPIOF_PIN2                  2
#define GPIOF_PIN3                  3
#define GPIOF_PIN4                  4
#define GPIOF_PIN5                  5
#define GPIOF_PIN6                  6
#define GPIOF_PIN7                  7
#define GPIOF_PIN8                  8
#define GPIOF_PIN9                  9
#define GPIOF_PIN10                 10
#define GPIOF_PIN11                 11
#define GPIOF_PIN12                 12
#define GPIOF_PIN13                 13
#define GPIOF_PIN14                 14
#define GPIOF_PIN15                 15
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

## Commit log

2015-10-28 Disabled QUEST as it is broken, reduced the number of calibration samples and did some further work on the mag rotation estimator.
    Also updated Frontier.Engine and the state estimator flowchart.
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2015-10-29 Created an empty KiCad project with separate sheets for the different sections people will be working on.
    [Altimeter.sch, IMU.sch, InertialSensors.sch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]
2015-10-29 PCB: add first draft of power supply
    Add a very basic linear regulator based power supply with 3V3 and 5V rails. Make
    use of the ADP3335 LDO regulator. The supply contains an external batter
    connector (no indicator yet) and supports powering the 5V rail via USB.
    Since the 5V rail can be powered either by battery or USB, make use of it to
    drive the 3V3 rail.
    [Power.sch]
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2015-10-29 PCB: update PSU schematic to latest kicad
    The original schematic was made with an ancient kicad. Fix it to be newer kicad
    friendly.
    [Power.sch]
2015-10-29 PCB: open and re-save power schematic with kicad nightly
    FSR the diode managed to be turned around.
    [Power.sch]
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2015-10-30 PCB: fix library path in fp-lib-table
    CPM made the mistake of using the wrong slash for directory separators and, like
    many other things from CPM, MS copied the error.
    Use the One True directory separator as revealed to us by the great prophet DMR.
    Less poetically: fix up fp-lib-table so that it doesn't break non-Windows
    machines.
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2015-10-30 PCB: add power flags to PSU
    [Power.sch]
2015-10-30 PSU: label polarity protection diode
    [Power.sch]
2015-11-02 Added Status Indicators work by Greg Brooks
    [StatusIndicators.sch]
2015-11-03 Added ADIS16405BMLZ schematic to InertialSensors sheet.
    [Altimeter.sch, IMU.sch, InertialSensors.sch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]
2015-11-03 Added SD card work by Luke Cockerton
    [Altimeter.sch, IMU.sch, InertialSensors.sch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]
2015-11-03 Added Altimeter work by Alex Clowes
    [Altimeter.sch, IMU.sch, InertialSensors.sch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]
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2015-11-04 PCB: fix up wandering components due to KiCad < 4
    On KiCad >= v4, components have shrunk. Fix up the positioning.
    [Altimeter.sch, IMU.sch, InertialSensors.sch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]
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2015-11-04 Added barebones Cortex-M4 schematic.
    [Altimeter.sch, IMU.sch, InertialSensors.sch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]
2015-11-04 PCB/IMU.sh: replace Earth symbols with Ground symbols
    Best be consistent!
    [IMU.sch]
2015-11-05 PCB/pin-assignments.md: correct name of SDIO_CK signal
2015-11-05 PCB/IMU.sch: add global labels for each pin assignment
    [IMU.sch]
2015-11-05 PCB/SDCard.sch: add SD Card global labels
    [SDCard.sch]
2015-11-05 PCB/IMU.sch: import hierarchical sheet pins for SD card
    [IMU.sch]
2015-11-05 PCB: wire up altimeter to SPI2
    [Altimeter.sch, IMU.sch]
2015-11-05 PCB: wire remaining components (excl. inertial sensor)
    [Altimeter.sch, IMU.sch, InertialSensors.sch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]
2015-11-05 PCB: add reset button circuit
    This is a copy of the circuit in Figure 38 of the STM32F4 datasheet.
    [IMU.sch]
2015-11-12 Added libraries and footprints from avionics14
    [Altimeter.sch, IMU.sch, InertialSensors.sch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]
2015-11-13 Revert to commit before last to fix bugs introduced by last commit
    [Altimeter.sch, IMU.sch, InertialSensors.sch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]
2015-11-15 PCB: tidy up psu
    [Power.sch]
2015-11-15 PCB: added sheet pins for inertial sensors
    [IMU.sch, InertialSensors.sch]
2015-11-15 wire IMU sensors to SPI1
    [IMU.sch]
2015-11-15 PCB: add UART1 and 2 ports
    [IMU.sch]
2015-11-15 PCB: add external SPI interface
    [IMU.sch]
2015-11-15 PCB: add test point to allow manual toggling of BOOT0
    [IMU.sch]
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2015-11-15 PCB: annotate schematic and remove unused SDIO pins
    [Altimeter.sch, IMU.sch, InertialSensors.sch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]
2015-11-15 ADIS16405: set pin types in library
    [InertialSensors.sch]
2015-11-15 PCB: fix remaining DRC issues
    [Altimeter.sch, IMU.sch, InertialSensors.sch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]
2015-11-15 PCB: update TODO (remove done items)
    [IMU.sch]
2015-11-15 PCB: assign some footprints
    These footprints are unlikely to be entirely correct. In particular, the choise
    of connectors is fairly arbitrary.
    [Altimeter.sch, IMU.sch, Power.sch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]
2015-11-15 PCB: add a PCB with all footprints on it
    [Altimeter.sch, IMU.kicad_pcb, IMU.sch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]
2015-11-16 PCB: place components around STM32
    Those components whose placing is required to be close to particular pads have
    been placed and routed.
    [IMU.kicad_pcb]
2015-11-16 PCB: align D1-6 with 0.5mm grid
    [IMU.kicad_pcb]
2015-11-16 PCB: swap some GPIO pin assignment to improve layout
    We have considerable freedom wrt GPIO pin locations. Route the inertial sensor's
    data ready line to a useful side of the chip.
    [IMU.kicad_pcb, IMU.sch]
2015-11-16 PCB: re-assign SD_CARD_DETECT signal to better side of STM32
    [IMU.kicad_pcb, IMU.sch]
2015-11-16 PCB: shuffle footprint and route some more uncontroversial tracks
    [Altimeter.sch, IMU.kicad_pcb, IMU.sch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]
2015-11-16 PCB: re-draw the ADIS16405 symbol to be less ugly
    [Altimeter.sch, IMU.sch, InertialSensors.sch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]
2015-11-16 PCB: add information on inertial sensor connector
    [Altimeter.sch, IMU.sch, InertialSensors.sch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]
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2015-11-16 PCB: fix footprint name of ADIS16450
    [InertialSensors.sch]
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2015-11-18 PCB: Power: add PTC fuse to protect USB bus from over current
    [Power.sch]
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2015-11-18 PCB: add xml2farnell.py script
    (Complete with unicode fixes)
2015-11-18 Add 2x4 pin header footprint for SPI connector
    [IMU.sch]
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2015-12-02 Update netlist and add component libraries to schematic
    [Altimeter.sch, IMU.kicad_pcb, IMU.sch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]
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2015-12-04 Edit design rules so mimimums are (at least) m2fc values
    [IMU.kicad_pcb]
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2015-12-05 Move components to likely final locations and adjust some trace widths
    [IMU.kicad_pcb]
2015-12-05 Begin routing SPI3 and place LEDs on board
    [IMU.kicad_pcb]
2015-12-07 Fixed mistake in prediciton step of orientation kalman filter.
2015-12-13 Move status LED outputs to pins 33 to 36 of the microcontroller
    [Altimeter.sch, IMU.kicad_pcb, IMU.sch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]
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2015-12-14 Fixed bug where the indices of the jacobians were swapped, resulting in rather strange behaviour.
    The filter now works very well, the only problem remaining is roll isn't always resolved correctly. I'm not sure this is a deficiency of the filter, however, as the magnetometer on the board I am using to test is not very good.
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2015-12-19 Reduced number of long traces in ground plane by shuffling a number of components around. Also reduced the length of the PCB as an added bonus.
    The silkscreen is currently messed up as a result of these changes - I've not had time to fix it.
    [Altimeter.sch, IMU.kicad_pcb, IMU.sch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]
2016-01-04 Altered the pinout to make the PCB somewhat cleaner.
    The changed pins are:
    nIMU moved to pin 40
    IMU moved to pin 39
    nSensors moved to pin 38
    Sensors moved to pin 37
    ADIS IRQ moved to pin 34
    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
    [Altimeter.sch, IMU.kicad_pcb, IMU.sch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]
2016-01-11 Added an MPU-9250 on the same SPI bus as the ADIS sensor. The PCB routing is a first draft and I may tweak it a bit further.
    I had to change the track spacing tolerance from 0.2mm to 0.19mm to be able to wire up the sensor.
    [Altimeter.sch, IMU.kicad_pcb, IMU.sch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]
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2016-01-20 Fix PCB mounting holes
    [IMU.kicad_pcb]
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2016-01-21 Minor changes to silkscreen and moved gerber files into their own directory
    [IMU-B.Cu.gbl, IMU-B.Mask.gbs, IMU-B.SilkS.gbo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]
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2016-01-28 Changed SD Card resistors to 47K and changed ADIS reset to be attached to a GPIO pin instead.
    [IMU.sch, InertialSensors.sch, SDCard.sch]
2016-01-28 Remove 3V3 loops, reroute LEDs and add board name/revision to silkscreen
    [IMU.kicad_pcb]
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2016-01-28 Removed remaining global labels and replaced with the appropriate combination of local labels and hierarchical labels.
    [IMU.sch, USB.sch]
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2016-01-28 Imported new netlist into PCBNew and placed new footprints.
    [IMU.kicad_pcb]
2016-01-28 Fix MPU-9250 footprint
    [IMU.kicad_pcb]
2016-01-28 Add farnell numbers for CAN and SPI headers
    [IMU.sch]
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2016-01-29 Rounded PCB corners, made minor changes to track routing and fixed up silkscreen
    [IMU.kicad_pcb]
2016-01-29 Updated MPU9250 schematic part to match MPU-9250
    Fixed directionality of hierarchical pins
    [Altimeter.sch, IMU.kicad_pcb, IMU.sch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]
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2016-01-29 Swapped capacitors C7 and C9 so the smaller of the two is closer to the stm32
    Minor silkscreen changes
    [IMU-B.Cu.gbl, IMU-B.Mask.gbs, IMU-B.SilkS.gbo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]
2016-01-31 Remove old Gerbers, add zip of gerbers sent to manufacturing.
    [IMU-B_Cu.gbl, IMU-B_Mask.gbs, IMU-B_SilkS.gbo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]
2016-02-02 Update BOM to add STM32F405VGT6 and 100n cap order codes
    [Altimeter.sch, IMU.sch, InertialSensors.sch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]
2016-02-02 Substitute some parts
    C3, C4 - swap to not insanely expensive caps, and fix value to 33pF
    C9, C26 - for some reason not purchasable on EDRS Marketplace. Replaced.
    P5 - Updated to actual Farnell order code
    R7 - Updated to less precise, cheaper 1k 0603 resistor
    USB connector - updated to single parts rather than reel of 500
    [IMU.sch, InertialSensors.sch, Power.sch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]
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2016-02-09 Fixed failing build due to renamed pins.
    [adis16405.c, main.c, mpu9250.c]
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2016-02-18 Initial PCB testing.
    MPU9250 not working and SD card untested, everything else appears to be working correctly.
    [main.c, mpu9250.c, ms5611.c]
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2016-03-13 firmware:mpu9250: fix typo 'sidable' => 'disable'
    [mpu9250.c]
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2016-03-14 firmware:mpu9250: re-factor mpu9250_burst_read
    Convert mpu9250_burst_read to read data into the buffer in-place. Should we be
    building on a big-endian device, this is all we need to do. Otherwise, we need
    to swap bytes.
    [mpu9250.c]
2016-03-14 firmware:mpu9250: re-factor self-test
    The previous implementation ran the gyroscope self test at the same time as the
    accelerometer self test. This is a Bad Idea since they may interfere with each
    other. Re-factor the code to do them sequentially. Also remove the needlessly
    complex mean-taking code.
    [mpu9250.c]
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2016-03-15 firmware:mpu9250: add minimal AK8963 information
    On the MPU9250, the magnetometer is a separate AK8963 within the same package.
    From peering at example code (and datasheets) it appears that this is controlled
    at arm's length via the MPU9250's I2C slave support.
    Note: this means out current mpu9250_burst_read() implementation is wrong.
    Add a list of AK8963 registers and the I2C address of the AK8963 packaged within
    the MPU9250.
    [mpu9250-reg.h]
2016-03-15 firmware:mpu9250: add missing register names
    Add the missing register names to mpu9250-reg.h.
    [mpu9250-reg.h]
2016-03-20 Added experimental messaging system. This will solves a number of problems the main two of which are decoupling the individual components of the system and removing the need for having to implement t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
    [main.c]
2016-03-20 Prevent main loop from terminating as for some reason it breaks USB when it does.
    [main.c]
2016-03-21 Replaced hard tabs with spaces
    [board.h]
2016-03-24 First draft implementation of new telemetry and messaging system. Very minimal testing has occurred so bugs are likely - I just want to get the changes stored.
    The GUI has not yet been updated and so won't compile
    [main.c]
2016-03-24 Fixed bug where message dispatch was using the number of initialized producers not consumers
    [main.c]
2016-03-25 Updated components to use new component state tracking facility. Fixed startup dependency cycle.
    [adis16405.c, main.c, mpu9250.c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]
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2016-03-30 Made MPU9250 driver interrupt driven.
    Fixed potential error loop in messaging system.
    Added ability to pause messaging delegates, optionally flushing all pending messages.
    Messaging consumer functions now return a boolean - allowing them to notify on error.
    Made USB telemetry driver sleep on failure to send, as this implies either we are writing too fast or the data isn't being read by the receiver.
    Made SerialDriver exit elegantly.
    [main.c, mpu9250.c]
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2016-04-26 First attempt to get MPU9250's magnetometer working - currently doesn't work at all.
    [mpu9250-reg.h, mpu9250.c]
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2016-06-04 Redesigned system for declaring messaging producers to make it clearer and to add categories
    [mpu9250.c, ms5611.c]
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2016-08-05 Orientation state estimation using the mpu9250 is now fully implemented and working very well. There is a slight bodge due to a sign error somewhere that I haven't been able to find
    Fixed GUI crash on exit if the SerialPort cannot be created correctly (doesn't exist)
    [main.c, mpu9250.c, ms5611.c]
2016-08-06 Revert "Travis CI build will now also compile the Avionics GUI" as remembered why I had it disabled: the lack of a linux serial driver.
    This reverts commit 6542059538d1b5badfd3ae4eea542c8da784b4e1.
2016-08-07 The heading-based magnetometer orientation estimation now correctly handles the discontinuity around heading 0 and seems to be working correctly now.
2016-08-11 Fixed rotation strange behaviour of kalman filter. The kalman filter computes the quaternion that rotates the reference vectors to line up with its observations which will be the inverse of the rotat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
    Added Avionics.GUI.Tests to test correctness/stability of the math_utils functions
2016-08-12 Added calibration system, currently only computes sensor bias but could easily be extended to compute other things (e.g covariance)
    Finally getting meaningful numbers from the mpu9250's magnetometer. I needed to use the Axis adjustment values stored in flash ROM, compensate for sensor bias and swap some of the axes around.
    [main.c, mpu9250.c]
2016-08-12 Further work getting magnetometer to work correctly
    [mpu9250.c]
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2016-08-19 Fix USB driver.
2016-08-19 m3imu now compiles correctly and should work
    [adis16405.c, board.h, halconf.h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]
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2016-08-20 ADIS driver now reading and writing registers correctly.
    Init will reset everything to remove any problems that might persist in flash from when it was not writing registers correctly.
    [adis16405.c, main.c]
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2016-08-26 MPU9250 data arriving over CAN->USB bridge and being rendered correctly
    [mpu9250.c]
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2016-10-31 Broke serial drivers out into separate library and created extractor program which dumps the MPU9250 data out to a file
2016-11-04 Fixed mistakes in quest implementation.
    It is currently thoroughly tested with perfect observations (i.e agree 100% with each other), additional tests need to be written for when it isn't fed such perfect data.
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2017-01-23 Tweaks to altitude tool to prevent dropping packets
    Fixed issue where ublox driver wouldn't wait long enough for the GPS to start up
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2017-02-15 Configured GUI to run state estimator - currently broken
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2017-02-15 Further work on kalman filter - currently still broken
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2017-03-09 Further work trying to isolate kalman filter's gyroscope problems
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2017-03-20 Minor optimisations to kalman filter and fixes to undefined behaviour in tests.
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2017-03-28 State estimator now corrects for inaccuracy in WMM declination.
    State estimator also estimates initial gyro bias
    Created centralised data plotting tool
2017-03-28 Further work on kalman filter
    Current issue is axis misalignment between magnetometer and accelerometer
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2017-04-01 Switched to using board with broken SD as magnetometer slightly less dreadfull
    Miscellaneous updates and tweaks to kalman filter
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2017-04-10 Removed unnecessary kalman states - fixes to wmm_util
    [main.c]
2017-04-12 Minor corrections to Kalman Filter and World Magnetic Model
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2017-09-20 Fixed ommitted JTAG reset pin
    [board.h]

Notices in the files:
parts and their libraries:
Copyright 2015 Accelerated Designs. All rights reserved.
